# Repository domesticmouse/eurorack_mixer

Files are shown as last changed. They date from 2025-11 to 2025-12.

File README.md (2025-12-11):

# Eurorack Mixer

This is a Eurorack module for mixing signals, using a
[TL074](https://www.ti.com/product/TL074).
It is based on the ES x MKI mixer.

**Note:** This is a learning exercise.

[KiCanvas rendering of the mainboard](https://kicanvas.org/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)

## Parts

| LCSC Part | Name | Description |
| --- | --- | --- |
| [C55071](https://www.lcsc.com/product-detail/C55071.html) | BOURNS 3224W-1-203E | POT 20kΩ 250mW SMD-3P,4.8x3.5mm |
| [C12594](https://www.lcsc.com/product-detail/C12594.html) | TI TL074CDR | LOW-NOISE JFET-INPUT OPERATIONAL AMPLIFIERS |
| [C311666](https://www.lcsc.com/product-detail/C311666.html) | Lelon OVK470M1ETR-0606 | CAP ALUM POLY 47uF ±20% 25V SMD |
| [C49678](https://www.lcsc.com/product-detail/C49678.html) | YAGEO CC0805KRX7R9BB104 | CAP CER 100nF 50V X7R 0805 |
| [C64982](https://www.lcsc.com/product-detail/C64982.html) | MDD(Microdiode Semiconductor) B340A | DIODE SCHOTTKY 40V SMA(DO-214AC) |
| [C19171391](https://www.lcsc.com/product-detail/C19171391.html) | YONGYUTAI YLED0805R | LED RED 0805 SMD |
| [C82544](https://www.lcsc.com/product-detail/C82544.html) | DIODES 1N5819HW-7-F | 25A 1 Independent 40V 450mV@1A 1A SOD-123 Single Diodes |
| [C573025](https://www.lcsc.com/product-detail/C573025.html) | Eurorack Power Connector | CONN IDC HEADER TH 10POS 2.54mm |
| [C17513](https://www.lcsc.com/product-detail/C17513.html) | UNI-ROYAL 0805W8F1001T5E | RES 1kΩ ±1% 125mW 0805 |
| [C149504](https://www.lcsc.com/product-detail/C149504.html) | UNI-ROYAL 0805W8F1003T5E | RES 100kΩ ±1% 125mW 0805 |
| [C17593](https://www.lcsc.com/product-detail/C17593.html) | UNI-ROYAL 0805W8F2702T5E | RES 27kΩ ±1% 125mW 0805 |
| [C17903](https://www.lcsc.com/product-detail/C17903.html) | UNI-ROYAL 1206W4F100JT5E | RES 10Ω ±1% 250mW 1206 |

## Sources

- [AI002 DIY Synthesizer Mixer Module Build Guide](https://aisynthesis.com/ai002-diy-eurorack-mixer-module-build/)
- [AI002 Schematic](https://aisynthesis.com/wp-content/uploads/2018/10/AI002-Mixer-Schematic-2.pdf)
- [ES x MKI EDU DIY Mixer](https://www.ericasynths.lv/shop/diy-kits-1/edu-diy-mixer/)
- [ES x MKI EDU DIY Mixer Manual](https://www.ericasynths.lv/media/MIXER_MANUAL.pdf)
- [Moritz Klein](https://www.youtube.com/@MoritzKlein0)'s
  [Designing a 3-channel mixer with diode distortion from scratch](https://www.youtube.com/watch?v=q8tmUgaXrEQ)
- [TL074 data sheet](https://www.ti.com/lit/ds/symlink/tl074.pdf)
- [EuroRack dimensions](https://midisoft.de/EuroRackDimensions/EuroRack_Dimensions.html)
- [Eurorack Panel Dimensions](https://www.exploding-shed.com/manuals-tutorials/manuals/standards-of-eurorack/eurorack-dimensions/)
- [Doepfer A100 DIY](https://doepfer.de/DIY/a100_diy.htm)
- [benjiaomodular](https://benjiaomodular.com/)'s [MiniAttenuMix](https://benjiaomodular.com/post/2023-11-08-miniattenumix/)

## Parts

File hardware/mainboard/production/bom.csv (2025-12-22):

Designator | Footprint | Quantity | Value | LCSC Part #
C1, C2 | CP_Elec_6.3x5.9 | 2 | 47uF 16v
C3, C4, C5, C6 | 0805 | 4 | 0.1uF
D1, D2 | D_SOD-323F | 2 | 20V
D3, D4 | 0805 | 2 | Red
D5, D6 | D_SOD-123 | 2 | Signal
J1 | IDC-Header_2x05_P2.54mm_Vertical | 1 | Power Connector
R1, R10, R11, R2, R9 | 0805 | 5 | 1k
R12, R15, R3, R4, R5, R6, R7, R8 | 0805 | 8 | 100k
R13 | 0805 | 1 | 27k
R14, R16 | 1206 | 2 | 10Ω
RV4 | Potentiometer_Bourns_3224W_Vertical | 1 | 20k
TP1 | TestPoint_Keystone_5000-5004_Miniature | 1 | TP_+12V
TP2 | TestPoint_Keystone_5000-5004_Miniature | 1 | TP_-12V
TP3, TP5 | TestPoint_Keystone_5000-5004_Miniature | 2 | TP_GND
TP7 | TestPoint_Keystone_5000-5004_Miniature | 1 | TP_INV_OUT
TP8 | TestPoint_Keystone_5000-5004_Miniature | 1 | TP_OUT
TP9 | TestPoint_Keystone_5000-5004_Miniature | 1 | TP_CLIP_OUT
U1 | SOIC-14_3.9x8.7mm_P1.27mm | 1 | TL074

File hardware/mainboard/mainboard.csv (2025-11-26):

Reference | Qty | Value | DNP | Exclude from BOM | Exclude from Board | Footprint | Datasheet | LCSC_Part_No | Manufacturer | Manufacturer_Part_No
C1,C2 | 2 | 47uF 16v |  |  |  | Capacitor_SMD:CP_Elec_6.3x5.9 | https://www.lcsc.com/datasheet/C311666.pdf | C311666 | Lelon | OVK470M1ETR-0606
C3,C4,C5,C6 | 4 | 0.1uF |  |  |  | Capacitor_SMD:C_0805_2012Metric_Pad1.18x1.45mm_HandSolder | https://www.lcsc.com/datasheet/C49678.pdf | C49678 | YAGEO | CC0805KRX7R9BB104
D1,D2 | 2 | 20V |  |  |  | Diode_SMD:D_SOD-323F | https://www.lcsc.com/datasheet/C114696.pdf | C114696 | Nexperia | BAT46WJ,115
D3,D4 | 2 | Red |  |  |  | LED_SMD:LED_0805_2012Metric_Pad1.15x1.40mm_HandSolder | https://www.lcsc.com/datasheet/C19171391.pdf | C19171391 | YONGYUTAI | YLED0805R
D5,D6 | 2 | Signal |  |  |  | Diode_SMD:D_SOD-123 | https://www.lcsc.com/datasheet/C82544.pdf | C82544 | DIODES | 1N5819HW-7-F
J1 | 1 | Power Connector |  |  |  | Connector_IDC:IDC-Header_2x05_P2.54mm_Vertical | https://www.lcsc.com/datasheet/C573025.pdf | C573025 | TE Connectivity | 1761681-3
J2,J3,J4,J5,J6,J7 | 6 | CLIP OUT,IN1,IN2,IN3,INV OUT,OUT |  | Excluded from BOM |  | EurorackFootprints:Jack_3.5mm_WQP-PJ398SM_Vertical_Tight
R1,R2,R9,R10,R11 | 5 | 1K,1k |  |  |  | Resistor_SMD:R_0805_2012Metric_Pad1.20x1.40mm_HandSolder | ~ | C17513 | UNI-ROYAL | 0805W8F1001T5E
R3,R4,R5,R6,R7,R8,R12,R15 | 8 | 100k |  |  |  | Resistor_SMD:R_0805_2012Metric_Pad1.20x1.40mm_HandSolder | ~ | C149504 | UNI-ROYAL | 0805W8F1003T5E
R13 | 1 | 27k |  |  |  | Resistor_SMD:R_0805_2012Metric_Pad1.20x1.40mm_HandSolder | ~ | C17593 | UNI-ROYAL | 0805W8F2702T5E
RV1,RV2,RV3 | 3 | 100k |  | Excluded from BOM |  | Potentiometer_THT:Potentiometer_Alpha_RD901F-40-00D_Single_Vertical | ~
RV4 | 1 | 20k |  |  |  | Potentiometer_SMD:Potentiometer_Bourns_3224W_Vertical | ~ | C55071 | BOURNS | 3224W-1-203E
TP1,TP2,TP3,TP5,TP7,TP8,TP9 | 7 | TP_+12V,TP_-12V,TP_CLIP_OUT,TP_GND,TP_INV_OUT,TP_OUT |  |  |  | TestPoint:TestPoint_Keystone_5000-5004_Miniature | ~ | C5199801 | ronghe | RH-5001
U1 | 1 | TL074 |  |  |  | Package_SO:SOIC-14_3.9x8.7mm_P1.27mm | http://www.ti.com/lit/ds/symlink/tl071.pdf | C12594 | TI | TL074CDR

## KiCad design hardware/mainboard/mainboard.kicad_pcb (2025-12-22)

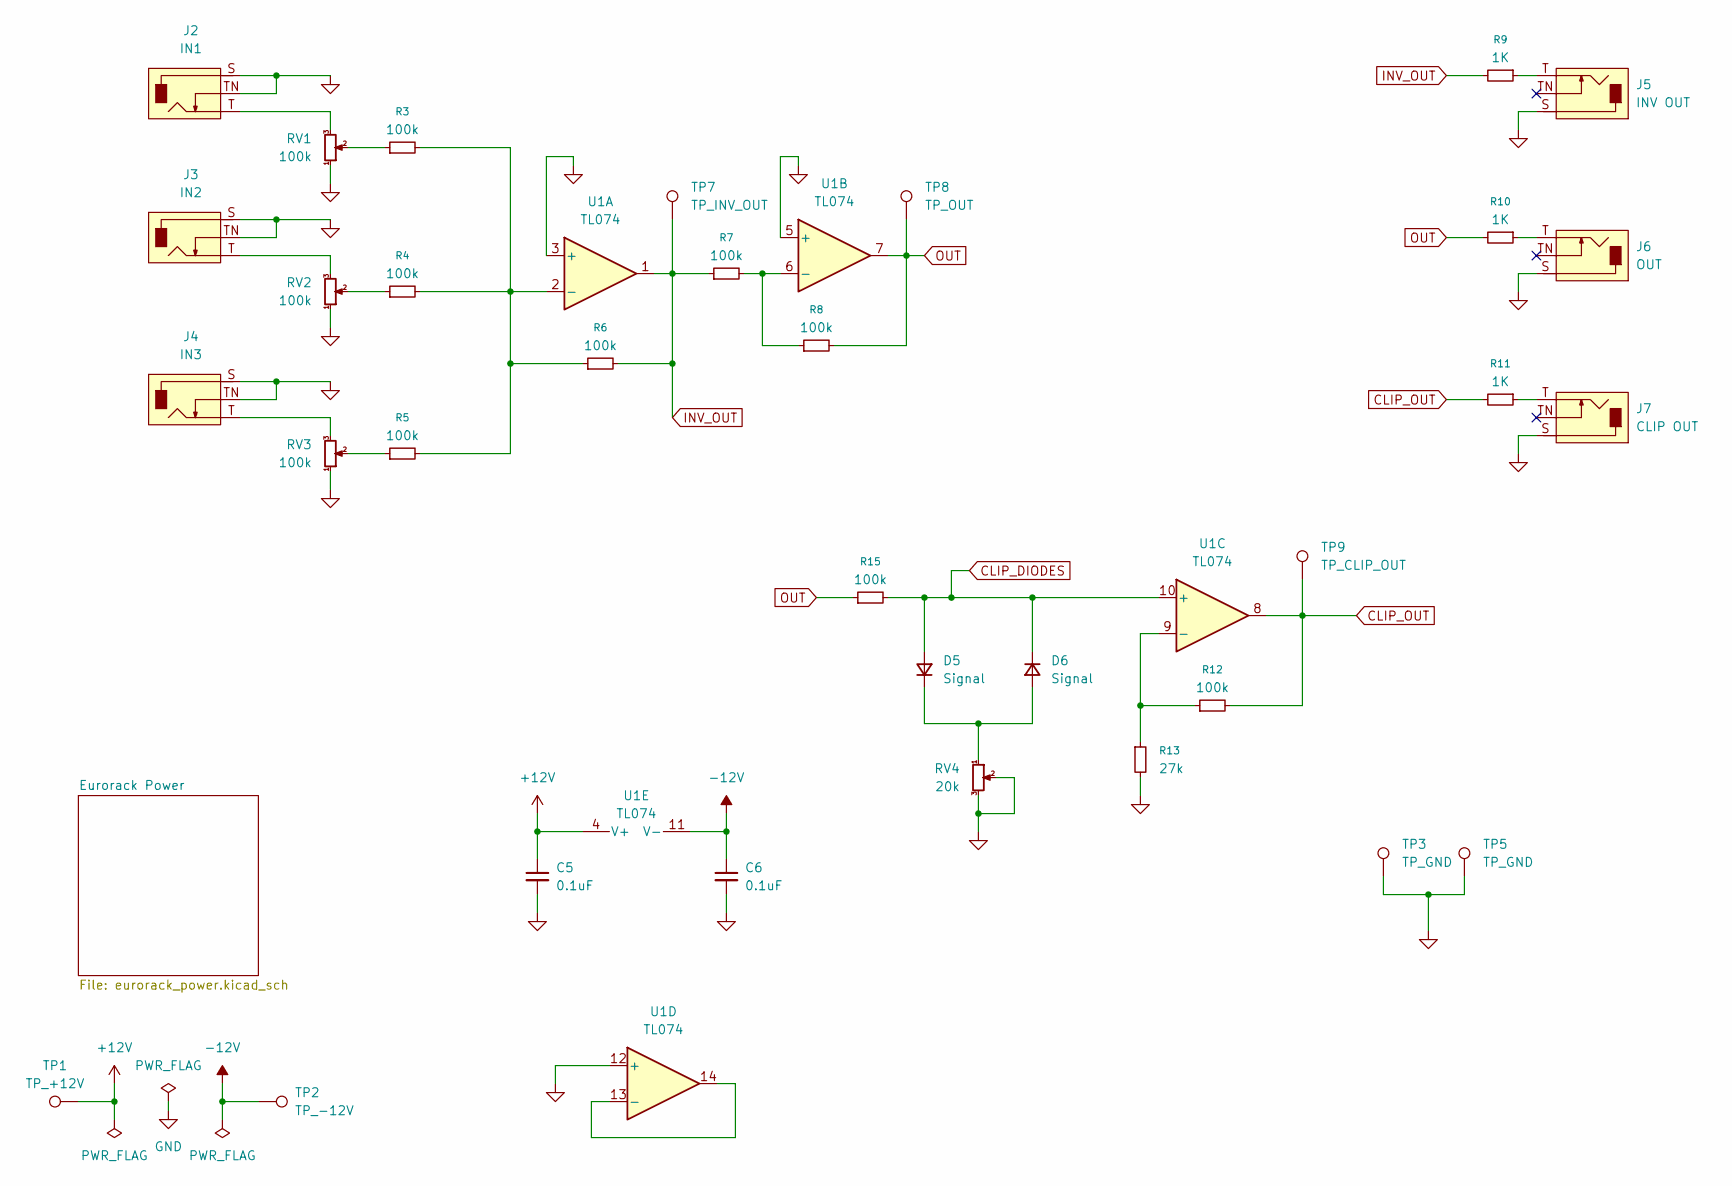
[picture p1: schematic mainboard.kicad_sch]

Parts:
C5, C6: 0.1uF; C_0805_2012Metric_Pad1.18x1.45mm_HandSolder; Manufacturer_Part_No CC0805KRX7R9BB104; LCSC_Part_No C49678
D5, D6: Signal; D_SOD-123; Manufacturer_Part_No 1N5819HW-7-F; LCSC_Part_No C82544
J2: IN1; Jack_3.5mm_WQP-PJ398SM_Vertical_Tight
J3: IN2; Jack_3.5mm_WQP-PJ398SM_Vertical_Tight
J4: IN3; Jack_3.5mm_WQP-PJ398SM_Vertical_Tight
J5: INV OUT; Jack_3.5mm_WQP-PJ398SM_Vertical_Tight
J6: OUT; Jack_3.5mm_WQP-PJ398SM_Vertical_Tight
J7: CLIP OUT; Jack_3.5mm_WQP-PJ398SM_Vertical_Tight
R3, R4, R5, R6, R7, R8, R12, R15: 100k; R_0805_2012Metric_Pad1.20x1.40mm_HandSolder; Manufacturer_Part_No 0805W8F1003T5E; LCSC_Part_No C149504
R9, R10, R11: 1K; R_0805_2012Metric_Pad1.20x1.40mm_HandSolder; Manufacturer_Part_No 0805W8F1001T5E; LCSC_Part_No C17513
R13: 27k; R_0805_2012Metric_Pad1.20x1.40mm_HandSolder; Manufacturer_Part_No 0805W8F2702T5E; LCSC_Part_No C17593
RV1, RV2, RV3: 100k; Potentiometer_Alpha_RD901F-40-00D_Single_Vertical
RV4: 20k; Potentiometer_Bourns_3224W_Vertical; Manufacturer_Part_No 3224W-1-203E; LCSC_Part_No C55071
TP1: TP_+12V; TestPoint_Keystone_5000-5004_Miniature; Manufacturer_Part_No RH-5001; LCSC_Part_No C5199801
TP2: TP_-12V; TestPoint_Keystone_5000-5004_Miniature; Manufacturer_Part_No RH-5001; LCSC_Part_No C5199801
TP3, TP5: TP_GND; TestPoint_Keystone_5000-5004_Miniature; Manufacturer_Part_No RH-5001; LCSC_Part_No C5199801
TP7: TP_INV_OUT; TestPoint_Keystone_5000-5004_Miniature; Manufacturer_Part_No RH-5001; LCSC_Part_No C5199801
TP8: TP_OUT; TestPoint_Keystone_5000-5004_Miniature; Manufacturer_Part_No RH-5001; LCSC_Part_No C5199801
TP9: TP_CLIP_OUT; TestPoint_Keystone_5000-5004_Miniature; Manufacturer_Part_No RH-5001; LCSC_Part_No C5199801
U1: TL074; SOIC-14_3.9x8.7mm_P1.27mm; Manufacturer_Part_No TL074CDR; LCSC_Part_No C12594

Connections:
+12V: C5.1, TP1.1, U1.4 (V+); also elsewhere on the board
-12V: C6.1, TP2.1, U1.11 (V-); also elsewhere on the board
CLIP_DIODES: D5.2 (A), D6.1 (K), R15.2, U1.10 (+)
CLIP_OUT: R11.2, R12.2, TP9.1, U1.8
GND: C5.2, C6.2, J2.S, J2.TN, J3.S, J3.TN, J4.S, J4.TN, J5.S, J6.S, J7.S, R13.2, RV1.1, RV2.1, RV3.1, RV4.2, RV4.3, TP3.1, TP5.1, U1.3 (+), U1.5 (+), U1.12 (+); also elsewhere on the board
INV_OUT: R6.2, R7.1, R9.2, TP7.1, U1.1
unnamed: D5.1 (K), D6.2 (A), RV4.1
unnamed: J2.T, RV1.3
unnamed: J3.T, RV2.3
unnamed: J4.T, RV3.3
unnamed: J5.T, R9.1
unnamed: J6.T, R10.1
unnamed: J7.T, R11.1
unnamed: R3.1, RV1.2
unnamed: R4.1, RV2.2
unnamed: R5.1, RV3.2
unnamed: R3.2, R4.2, R5.2, R6.1, U1.2 (-)
unnamed: R7.2, R8.1, U1.6 (-)
unnamed: R12.1, R13.1, U1.9 (-)
unnamed: U1.13 (-), U1.14
OUT: R8.2, R10.2, R15.1, TP8.1, U1.7

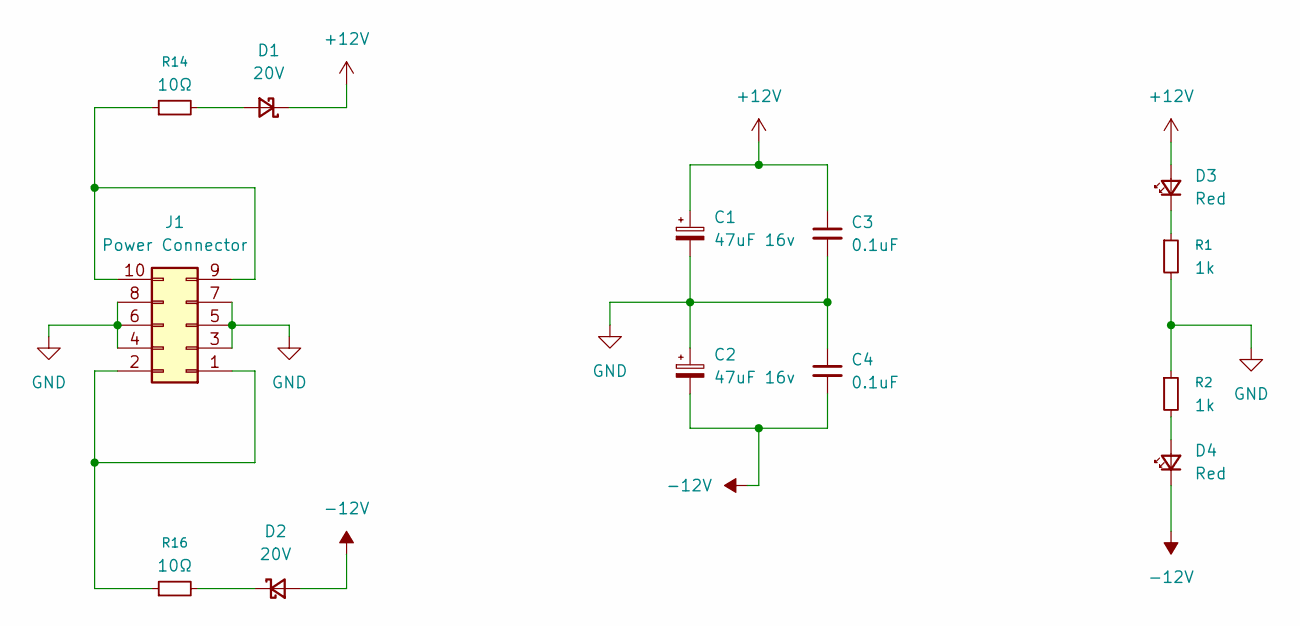
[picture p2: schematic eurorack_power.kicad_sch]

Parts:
C1, C2: 47uF 16v; CP_Elec_6.3x5.9; Manufacturer_Part_No OVK470M1ETR-0606; LCSC_Part_No C311666
C3, C4: 0.1uF; C_0805_2012Metric_Pad1.18x1.45mm_HandSolder; Manufacturer_Part_No CC0805KRX7R9BB104; LCSC_Part_No C49678
D1, D2: 20V; D_SOD-323F; Manufacturer_Part_No BAT46WJ,115; LCSC_Part_No C114696
D3, D4: Red; LED_0805_2012Metric_Pad1.15x1.40mm_HandSolder; Manufacturer_Part_No YLED0805R; LCSC_Part_No C19171391
J1: Power Connector; IDC-Header_2x05_P2.54mm_Vertical; Manufacturer_Part_No 1761681-3; LCSC_Part_No C573025
R1, R2: 1k; R_0805_2012Metric_Pad1.20x1.40mm_HandSolder; Manufacturer_Part_No 0805W8F1001T5E; LCSC_Part_No C17513
R14, R16: 10Ω; R_1206_3216Metric_Pad1.30x1.75mm_HandSolder

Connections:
+12V: C1.1, C3.1, D1.1 (K), D3.2 (A); also elsewhere on the board
-12V: C2.2, C4.2, D2.2 (A), D4.1 (K); also elsewhere on the board
GND: C1.2, C2.1, C3.2, C4.1, J1.3, J1.4, J1.5, J1.6, J1.7, J1.8, R1.2, R2.1; also elsewhere on the board
unnamed: D1.2 (A), R14.2
unnamed: D2.1 (K), R16.2
unnamed: D3.1 (K), R1.1
unnamed: D4.2 (A), R2.2
unnamed: J1.1, J1.2, R16.1
unnamed: J1.9, J1.10, R14.1

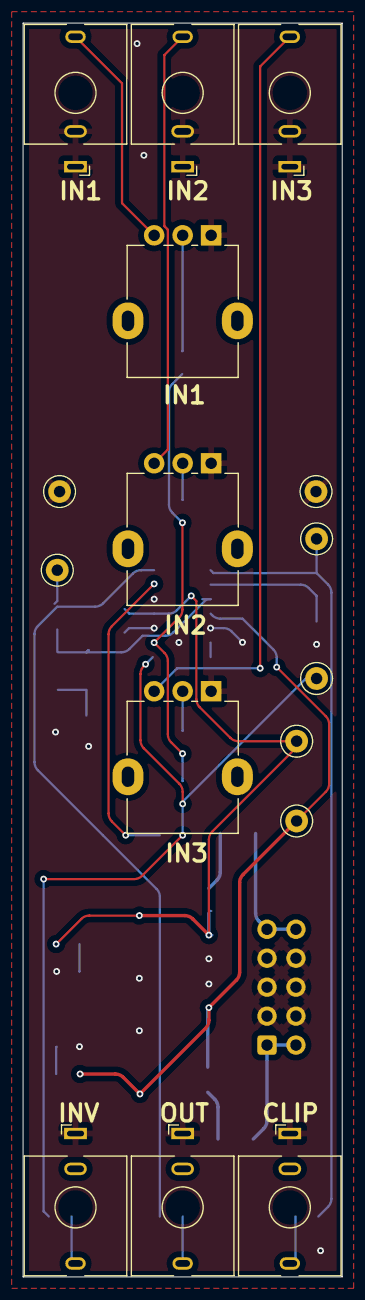
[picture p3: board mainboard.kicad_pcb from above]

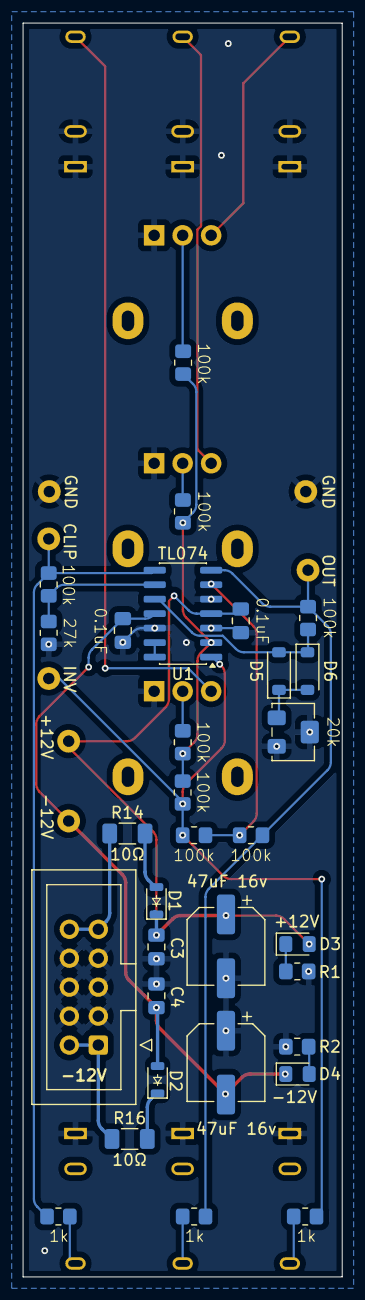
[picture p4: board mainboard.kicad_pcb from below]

Board: 2 copper layers, 28.0 x 110.0 mm, 47 parts (31 on the bottom side), 27 nets.

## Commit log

2025-11-25 Add power supply circuitry
    [eurorack_power.kicad_sch, mainboard.kicad_pcb, mainboard.kicad_sch]
2025-11-25 Add mixer circuitry
    [eurorack_power.kicad_sch, mainboard.kicad_sch]
2025-11-25 Add footprints
    [eurorack_power.kicad_sch, mainboard.kicad_sch]
2025-11-25 Clean up
    [mainboard.kicad_pcb, mainboard.kicad_sch]
2025-11-26 Add resistors
2025-11-26 Sent mainboard
    [bom.csv, designators.csv, eurorack_power.kicad_sch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]
2025-11-27 add measurements
    [faceplate.kicad_pcb]
2025-11-27 Add adornment to the faceplate
    [faceplate.kicad_pcb]
2025-12-04 Up size the faceplate drill size for the pots
    [faceplate.kicad_pcb]
2025-12-04 Add 10Ω resistors to power rails
    [eurorack_power.kicad_sch, mainboard.kicad_pcb]
2025-12-06 Make SOD323F footprint easier to hand solder
2025-12-08 Add ioboard
    [ioboard.kicad_pcb, ioboard.kicad_sch, mainboard.kicad_pcb]
2025-12-09 Update `ioboard`
    [ioboard.kicad_pcb, ioboard.kicad_sch]
2025-12-09 Add labels
    [ioboard.kicad_pcb]
2025-12-10 Update dimensions
    [ioboard.kicad_pcb]
2025-12-10 Start of mixerboard
    [connectors.kicad_sch, mixerboard.kicad_pcb, mixerboard.kicad_sch]
2025-12-11 Update the barrier diode
2025-12-11 Add Eurorack power
    [connectors.kicad_sch]
2025-12-20 Re-arrange things
    [mainboard.kicad_pcb]
2025-12-22 remove `ioboard` and `mixerboard`
    [connectors.kicad_sch, ioboard.kicad_pcb, ioboard.kicad_sch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]
2025-12-22 Update `mainboard`
    [bom.csv, designators.csv, mainboard.kicad_pcb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]
